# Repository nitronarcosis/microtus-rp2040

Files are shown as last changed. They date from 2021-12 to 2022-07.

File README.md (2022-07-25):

#  What
Microtus is a miniature joystick/button/rotary encoder board designed to approximate the functionality of a traditional mouse. The idea was to create a small, independent board that would communicate with a keyboard over I^2^C. I designed two versions, one based on the RP2040 that should be able to run KMK or QMK (eventually), the other as a minimum viable product based on the ATtiny85 which was abandoned when I realized how backwards the chip market is and the much less capable ATtiny cost more than the RP2040.
#### Parts

 - 5-way analog joystick --- for 2d pointer control
 - low-profile Kailh Choc switches --- dedicated buttons for left/right click
 - 90°? Rotary encoder --- for scrolling
 - USB type C 2.0 --- for programming or independent use
 - JST SH 4-pin connector --- for connecting via I^2^C (ala Qwiic)

# Why

I build a cool new keyboard and wanted to see if I could design a "mouse" that was complementary.
#### Name
It's not a mouse but it's a genus of small-eared voles. It's related enough but not the same.

# Renders

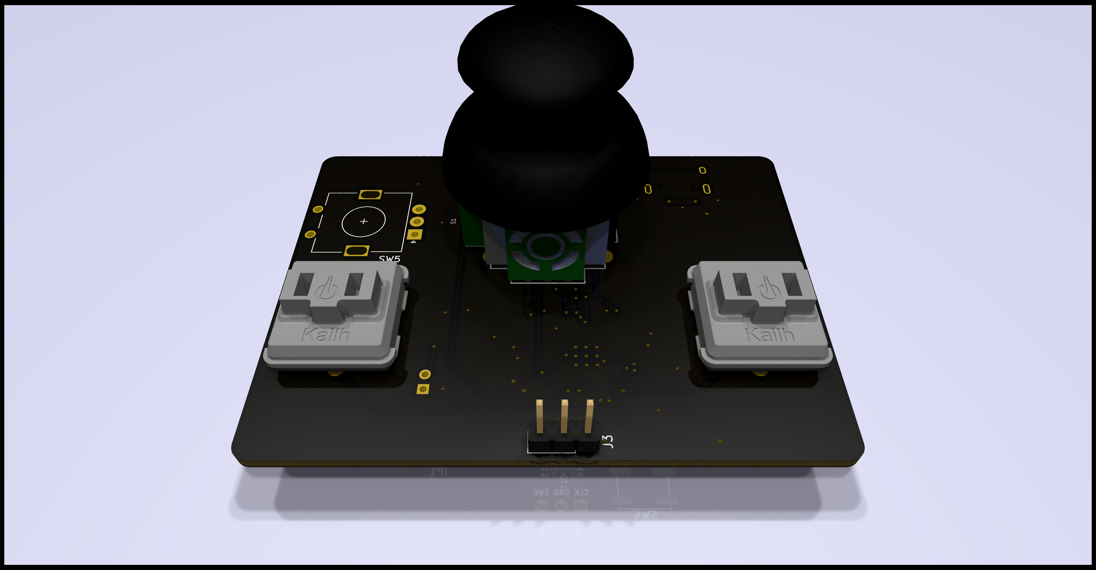
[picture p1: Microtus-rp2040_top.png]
Microtus RP2040 Top Render


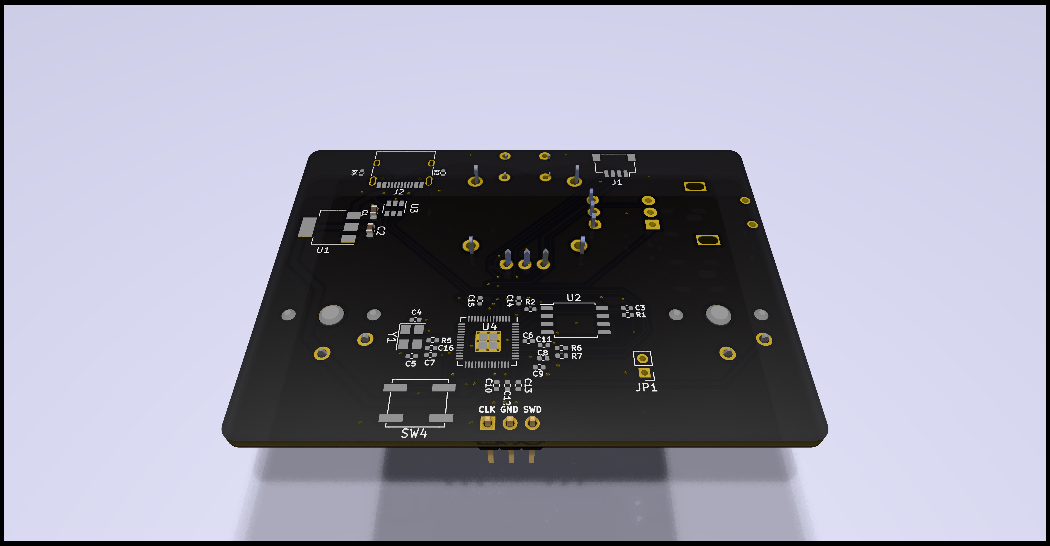
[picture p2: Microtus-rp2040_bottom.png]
Microtus RP2040 Bottom Render


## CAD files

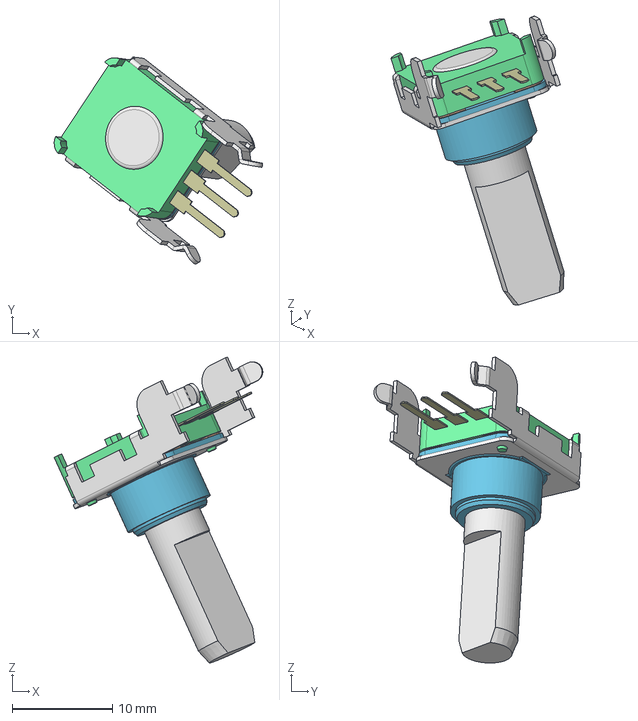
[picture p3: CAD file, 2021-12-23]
11CEY25F243A.stp
20.8 x 20.6 x 30.5 mm

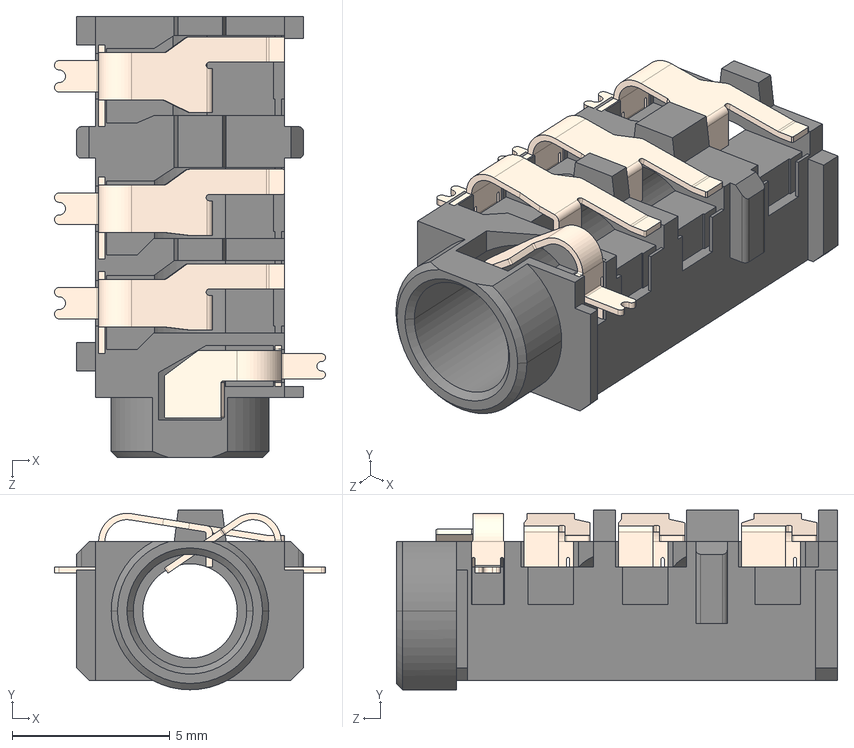
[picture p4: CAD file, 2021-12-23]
Footprints/Keebio-Parts.pretty-master/3dmodels/CUI_SJ-43614-SMT-TR.step
8.60 x 5.70 x 14.0 mm

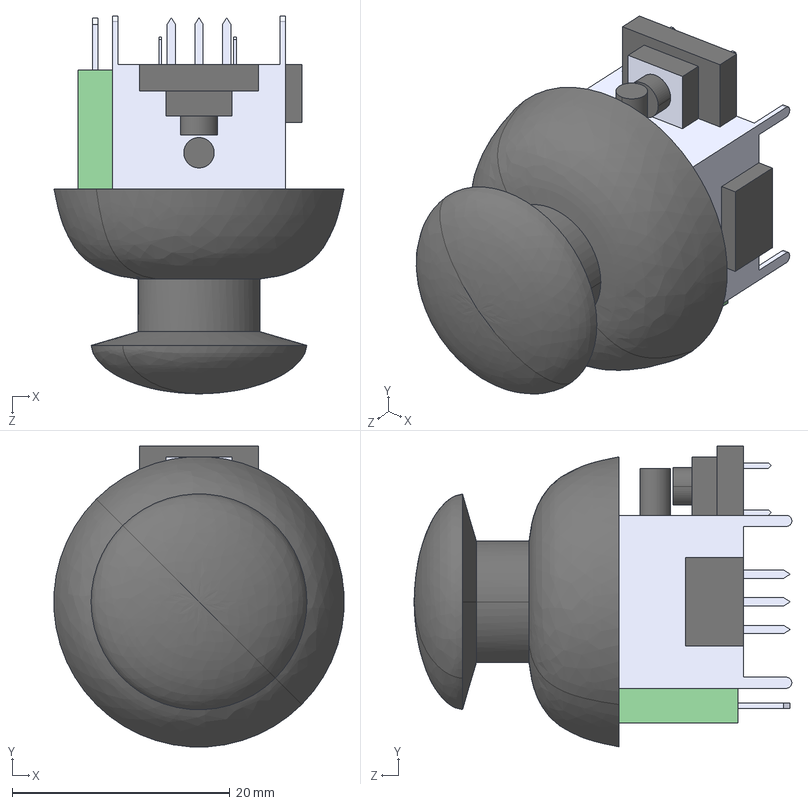
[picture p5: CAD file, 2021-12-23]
9032.STEP
26.6 x 27.6 x 34.7 mm

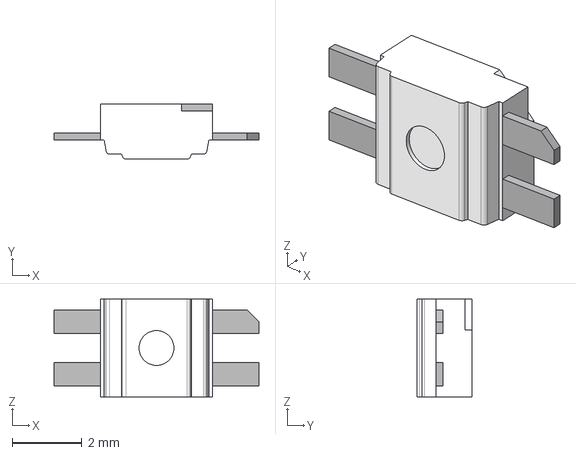
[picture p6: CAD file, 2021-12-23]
Footprints/Keebio-Parts.pretty-master/3dmodels/SK6812MINI-E v1.step
5.88 x 1.58 x 2.80 mm

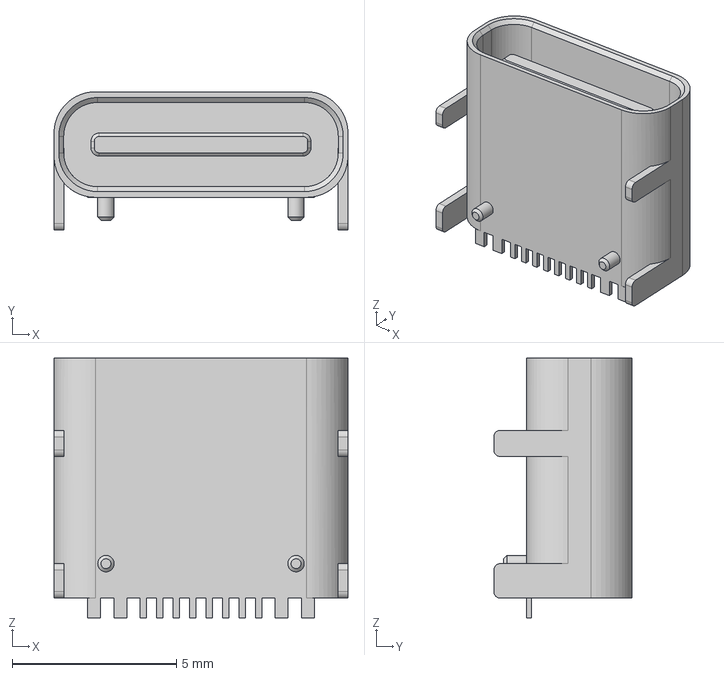
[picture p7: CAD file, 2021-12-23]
Footprints/Keebio-Parts.pretty-master/3dmodels/HRO TYPE-C-31-M-12.step
8.94 x 4.21 x 7.90 mm

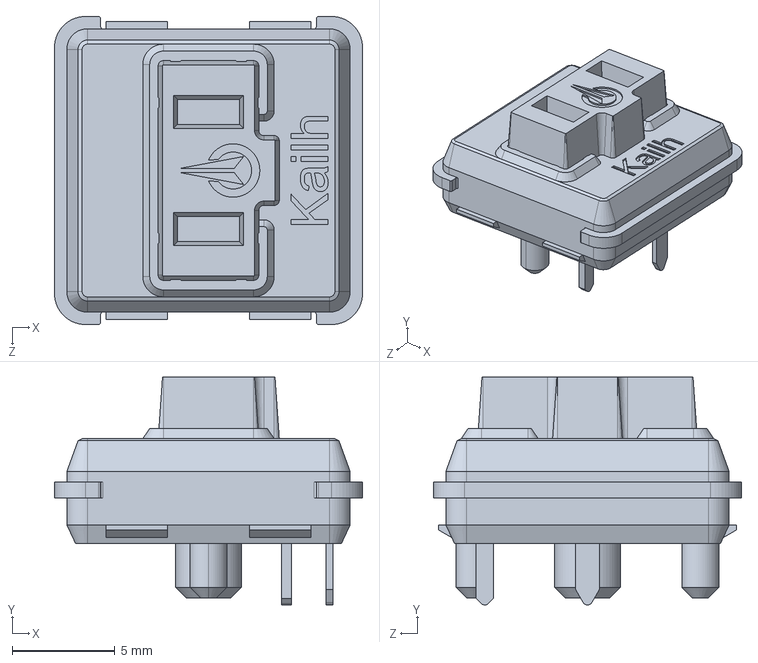
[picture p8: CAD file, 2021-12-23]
Kailh LP Choc Burnt Orange.STEP
15.0 x 11.1 x 15.0 mm

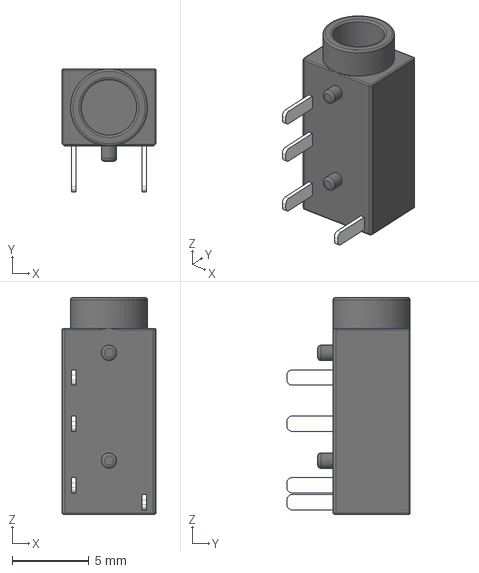
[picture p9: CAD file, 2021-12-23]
Footprints/Keebio-Parts.pretty-master/3dmodels/PJ-320A.step
6.10 x 8.00 x 14.1 mm

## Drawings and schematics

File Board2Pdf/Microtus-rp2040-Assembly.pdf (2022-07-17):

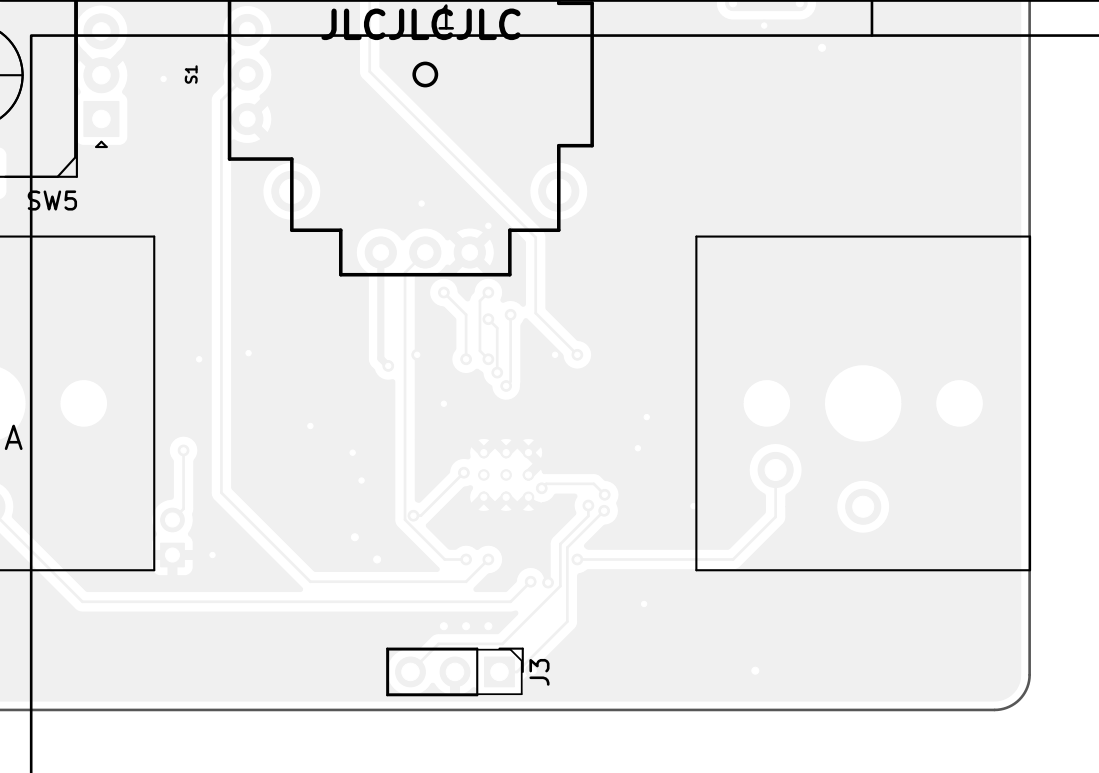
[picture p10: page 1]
JLCJLCJLC S¹ SW5; D Date: KiCad E.D.A. kicad (6.0.0) Size: A4; Rev:; Id: 1/1 Title:; File: Microtus-rp2040.kicad_pcb; Sheet: Assembly

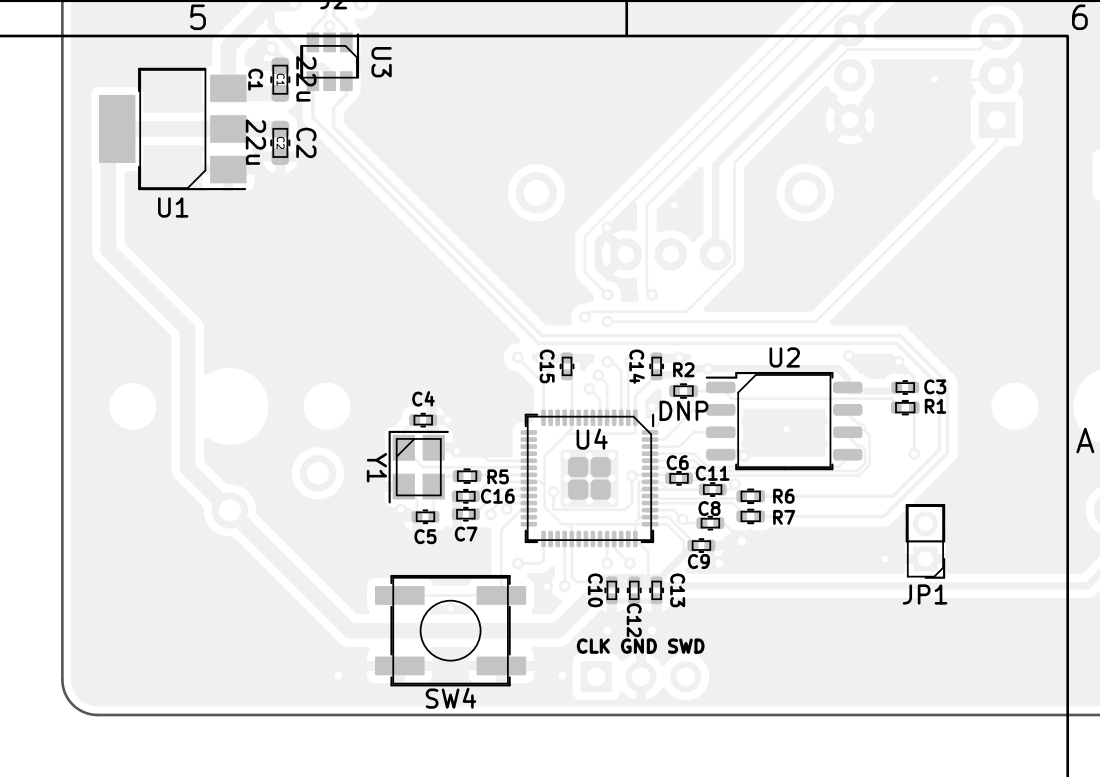
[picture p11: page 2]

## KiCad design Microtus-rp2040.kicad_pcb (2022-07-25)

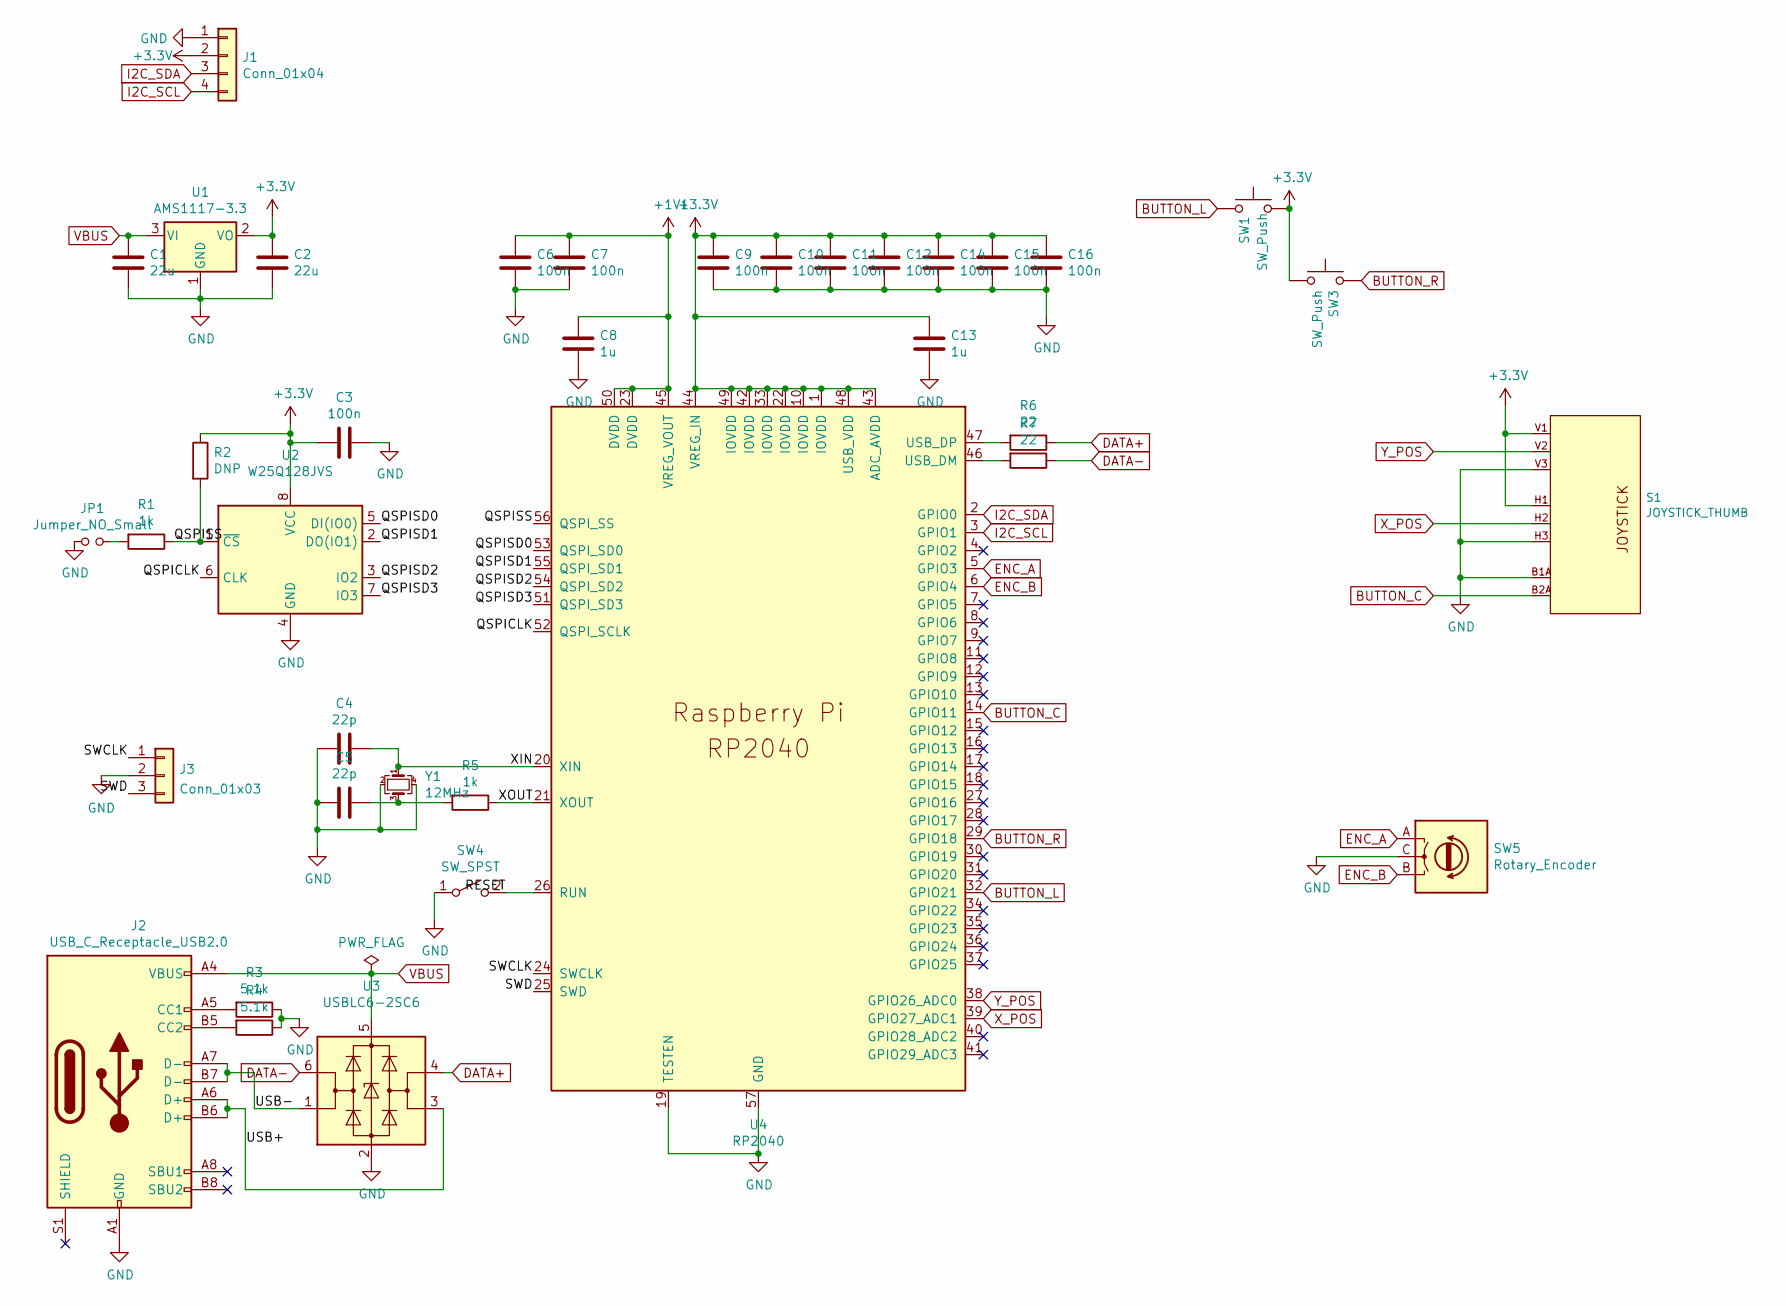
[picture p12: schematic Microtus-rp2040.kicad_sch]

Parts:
C1, C2: 22u; C_0603_1608Metric; LCSC C59461
C3, C6, C7, C9, C10, C11, C12, C14, C15, C16: 100n; C_0402_1005Metric; LCSC C1525
C4, C5: 22p; C_0402_1005Metric; LCSC C1555
C8, C13: 1u; C_0402_1005Metric; LCSC C52923
J1: Conn_01x04; JST_SH_SM04B-SRSS-TB_1x04-1MP_P1.00mm_Horizontal
J2: USB_C_Receptacle_USB2.0; USB_C_Receptacle_HRO_TYPE-C-31-M-12
J3: Conn_01x03; PinHeader_1x03_P2.54mm_Vertical
JP1: Jumper_NO_Small; PinHeader_1x02_P2.00mm_Vertical
R1, R5: 1k; R_0402_1005Metric; LCSC C11702
R2: DNP; R_0402_1005Metric
R3, R4: 5.1k; R_0402_1005Metric; LCSC C25905
R6, R7: 22; R_0402_1005Metric; LCSC C25092
S1: JOYSTICK_THUMB; JOYSTICK
SW1, SW3: SW_Push; Kailh-PG1350-1u-NoLED
SW4: SW_SPST; SW_SPST_EVQP0; LCSC C713479
SW5: Rotary_Encoder; RotaryEncoder_Alps_EC11E_Vertical_H20mm
U1: AMS1117-3.3; SOT-223-3_TabPin2; LCSC C6186
U2: W25Q128JVS; SOIC-8_5.23x5.23mm_P1.27mm; LCSC C97521
U3: USBLC6-2SC6; SOT-23-6; LCSC C2827654
U4: RP2040; RP2040-QFN-56; LCSC C2040
Y1: 12MHz; Crystal_SMD_3225-4Pin_3.2x2.5mm; LCSC C9002

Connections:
+1V1: C6.1, C7.1, C8.1, U4.23 (DVDD), U4.45 (VREG_VOUT), U4.50 (DVDD)
+3V3: C2.1, C3.2, C9.1, C10.1, C11.1, C12.1, C13.1, C14.1, C15.1, C16.1, J1.2, R2.1, S1.H1 (H+), S1.V1 (V+), SW1.2, SW3.1, U1.2 (VO), U2.8 (VCC), U4.1 (IOVDD), U4.10 (IOVDD), U4.22 (IOVDD), U4.33 (IOVDD), U4.42 (IOVDD), U4.43 (ADC_AVDD), U4.44 (VREG_IN), U4.48 (USB_VDD), U4.49 (IOVDD)
/QSPICLK: U2.6 (CLK), U4.52 (QSPI_SCLK)
/QSPISD0: U2.5 (DI(IO0)), U4.53 (QSPI_SD0)
/QSPISD1: U2.2 (DO(IO1)), U4.55 (QSPI_SD1)
/QSPISD2: U2.3 (IO2), U4.54 (QSPI_SD2)
/QSPISD3: U2.7 (IO3), U4.51 (QSPI_SD3)
/QSPISS: R1.1, R2.2, U2.1 (~CS), U4.56 (QSPI_SS)
/RESET: SW4.2 (B), U4.26 (RUN)
/SWCLK: J3.1, U4.24 (SWCLK)
/SWD: J3.3, U4.25 (SWD)
/USB+: J2.A6 (D+), J2.B6 (D+), U3.3 (I/O2)
/USB-: J2.A7 (D-), J2.B7 (D-), U3.1 (I/O1)
/XIN: C4.1, U4.20 (XIN), Y1.1
/XOUT: R5.1, U4.21 (XOUT)
BUTTON_L: SW1.1, U4.32 (GPIO21)
BUTTON_R: SW3.2, U4.29 (GPIO18)
DATA+: R6.1, U3.4 (I/O2)
DATA-: R7.1, U3.6 (I/O1)
ENC_A: SW5.A, U4.5 (GPIO3)
ENC_B: SW5.B, U4.6 (GPIO4)
I2C_SCL: J1.4, U4.3 (GPIO1)
I2C_SDA: J1.3, U4.2 (GPIO0)
unnamed: C5.1, R5.2, Y1.3
unnamed: J2.A5 (CC1), R3.2
unnamed: J2.B5 (CC2), R4.2
unnamed: JP1.2, R1.2
unnamed: R6.2, U4.47 (USB_DP)
unnamed: R7.2, U4.46 (USB_DM)
VBUS: C1.1, J2.A4 (VBUS), J2.A9 (VBUS), J2.B4 (VBUS), J2.B9 (VBUS), U1.3 (VI), U3.5 (VBUS)
X_POS: S1.H2 (H), U4.39 (GPIO27_ADC1)
Y_POS: S1.V2 (V), U4.38 (GPIO26_ADC0)

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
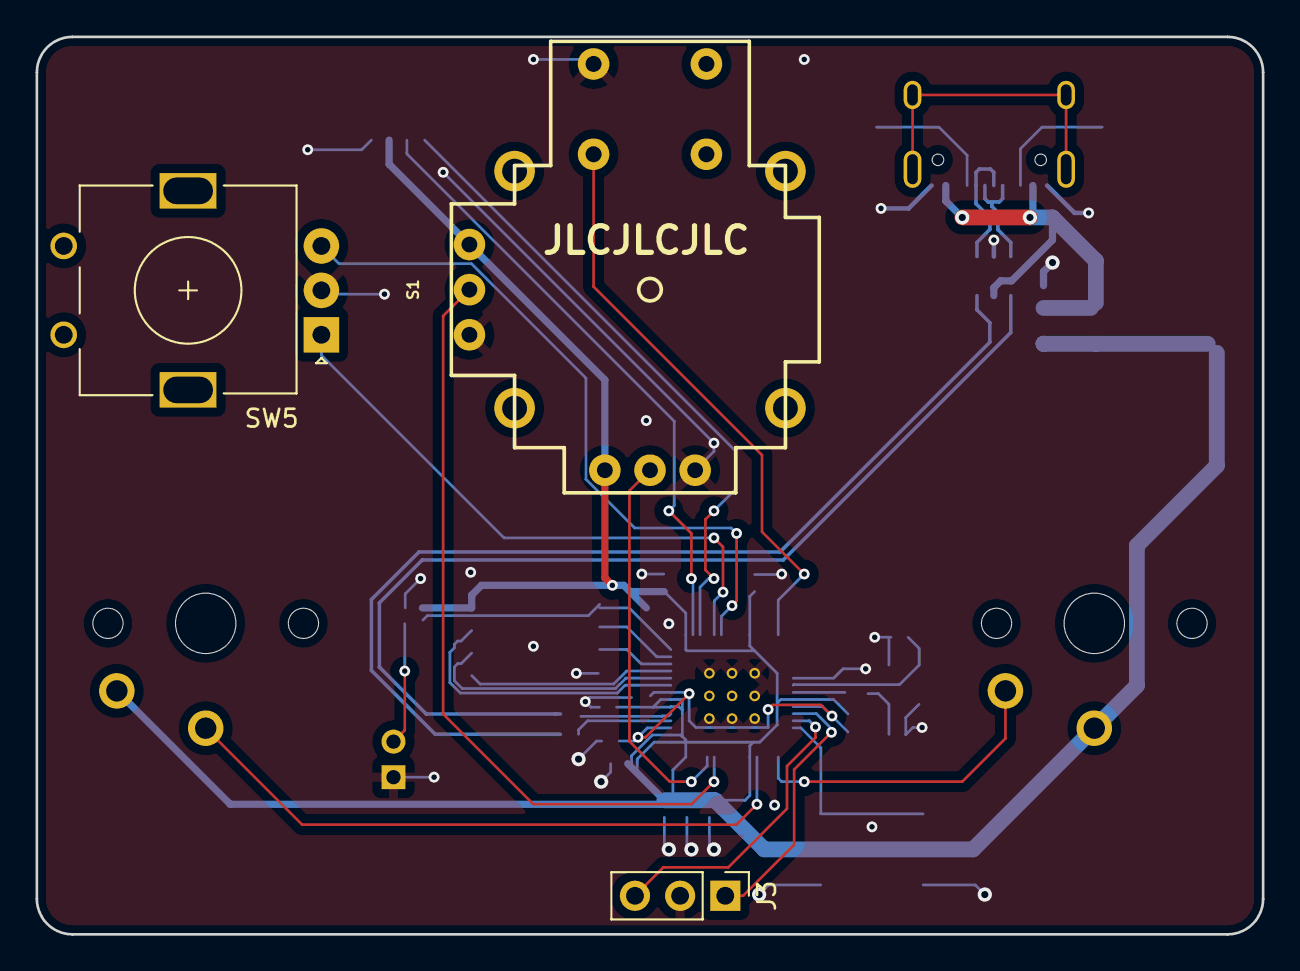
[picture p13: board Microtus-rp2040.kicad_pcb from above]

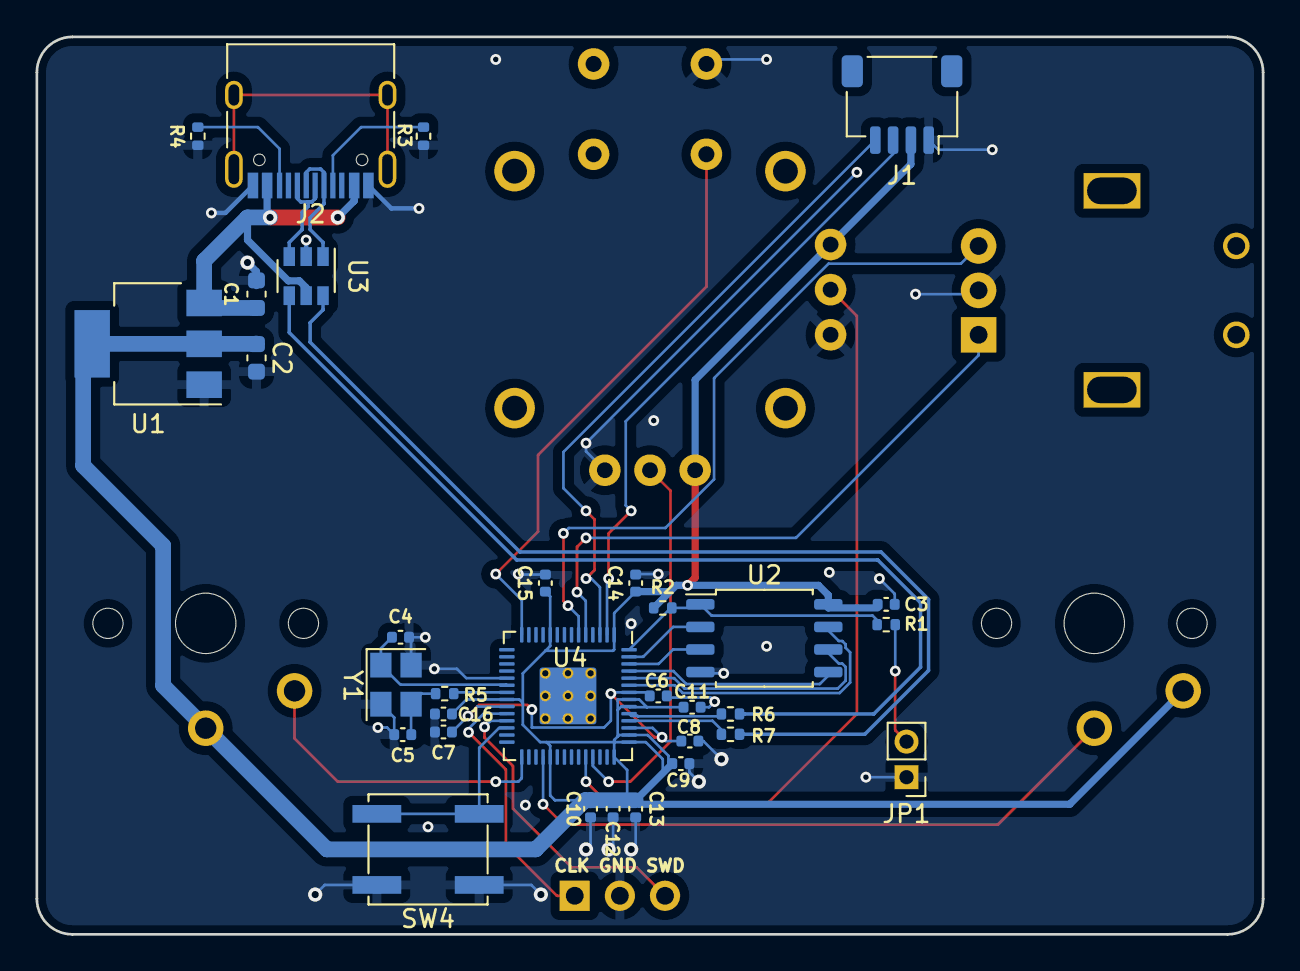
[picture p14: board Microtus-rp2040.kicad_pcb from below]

Board: 2 copper layers, 69.0 x 50.5 mm, 37 parts (32 on the bottom side), 34 nets.

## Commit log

2021-12-26 moving things around
    [Microtus-rp2040.kicad_pcb, Microtus-rp2040.sch]
2021-12-27 add SWD and switch to KiCad 6
    [Microtus-rp2040.kicad_pcb, Microtus-rp2040.kicad_sch]
2021-12-27 Generate production files
    [Microtus-rp2040-B_Cu.gbl, Microtus-rp2040-B_Mask.gbs, Microtus-rp2040-B_Paste.gbp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]
2022-07-25 Adding pictures, and a README!!
    [Microtus-rp2040.kicad_pcb, Microtus-rp2040.kicad_sch]
